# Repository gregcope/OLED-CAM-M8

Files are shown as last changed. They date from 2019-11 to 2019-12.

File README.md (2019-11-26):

# OLED-CAM-M8
OLED / NEO CAM M8Q Board is designed to go above other boards so that;
1. The GNS has a large ground plane for its internal attenna
2. The GNS has nothing near its antenna so that it has a good view of the sky
3. The OLED is ontop

More to follow... if it works

# Version
1. OLED-CAM-M8_2019-11-25.zip sent to fab

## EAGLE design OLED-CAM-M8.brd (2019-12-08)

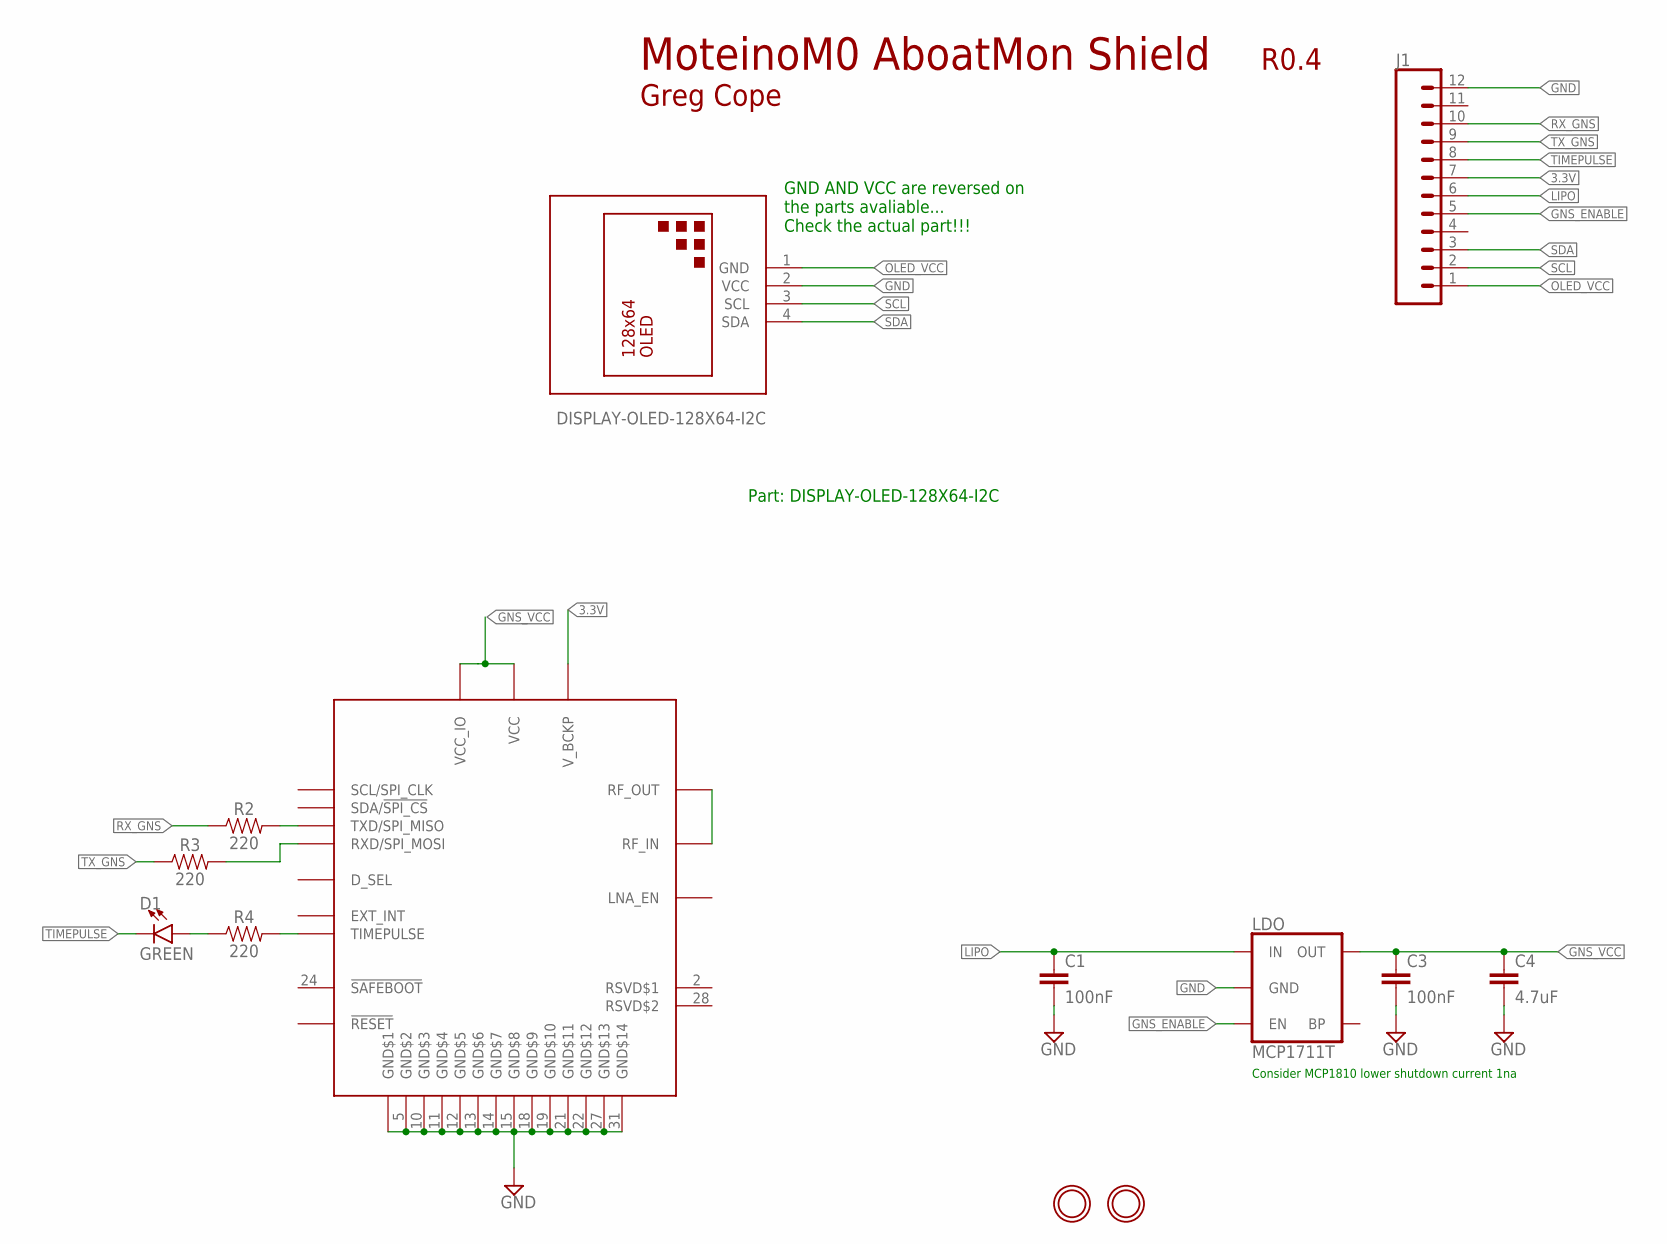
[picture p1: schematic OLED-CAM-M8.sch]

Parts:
C1, C3: 100nF; 0603
C4: 4.7uF; 0603
D1: GREEN; LED-0603
GND: MOUNTINGHOLE2.5; MOUNTINGHOLE_2.5_PLATED
J1: CONN_12; 1X12
LDO: MCP1711T; SOT23-5
R2, R3, R4: 220; 0603
U$2: DISPLAY-OLED-128X64-I2C
U$5: CAM-M8
U$7: MOUNTINGHOLE2.5; MOUNTINGHOLE_2.5_PLATED

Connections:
3.3V: J1.7, U$5.8 (V_BCKP)
GND: C1.2, C3.2, C4.2, J1.12, LDO.2 (GND), U$2.2 (VCC), U$5.4 (GND$1), U$5.5 (GND$2), U$5.10 (GND$3), U$5.11 (GND$4), U$5.12 (GND$5), U$5.13 (GND$6), U$5.14 (GND$7), U$5.15 (GND$8), U$5.18 (GND$9), U$5.19 (GND$10), U$5.21 (GND$11), U$5.22 (GND$12), U$5.27 (GND$13), U$5.31 (GND$14)
GNS_ENABLE: J1.5, LDO.3 (EN)
GNS_VCC: C3.1, C4.1, LDO.5 (OUT), U$5.1 (VCC_IO), U$5.9 (VCC)
LIPO: C1.1, J1.6, LDO.1 (IN)
unnamed: R4.2, U$5.29 (TIMEPULSE)
unnamed: R2.2, U$5.25 (TXD/SPI_MISO)
unnamed: R3.2, U$5.26 (RXD/SPI_MOSI)
unnamed: D1.A, R4.1
unnamed: U$5.16 (RF_OUT), U$5.17 (RF_IN)
OLED_VCC: J1.1, U$2.1 (GND)
RX_GNS: J1.10, R2.1
SCL: J1.2, U$2.3 (SCL)
SDA: J1.3, U$2.4 (SDA)
TIMEPULSE: D1.C, J1.8
TX_GNS: J1.9, R3.1

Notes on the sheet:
Greg Cope
R0.4
MoteinoM0 AboatMon Shield
Consider MCP1810 lower shutdown current 1na
Part: DISPLAY-OLED-128X64-I2C
GND AND VCC are reversed on the parts avaliable... Check the actual part!!!

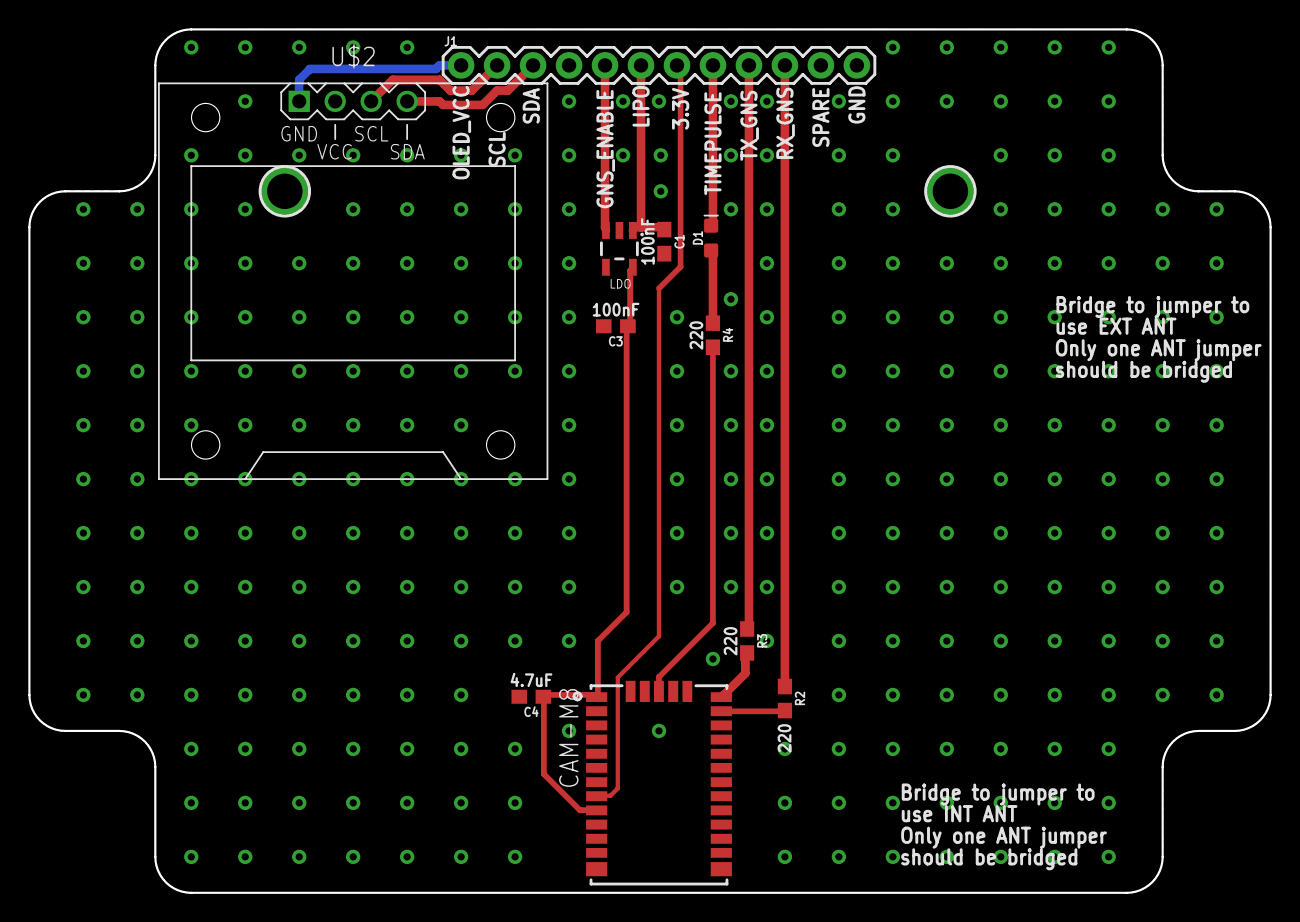
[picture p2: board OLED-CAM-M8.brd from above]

Board: 2 copper layers, 87.6 x 61.0 mm, 13 parts (0 on the bottom side), 16 nets.

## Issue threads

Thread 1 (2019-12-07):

OLED header / outline wrong

gregcope, 2019-12-07:
Header/outline is wrong for most OLEDs I have.

They are from left to right (from above);
VCC
GND
SCL
SDA

gregcope, 2019-12-08:
Swapped the Pins and left a note.  Seems some screens are supplied with pins swapped, others not.  Fixed(!) in 8a7cde8

Closed 2019-12-08.

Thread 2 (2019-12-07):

Mount holes do not line up

gregcope, 2019-12-07:
With this outline they do not line up

gregcope, 2019-12-08:
They do ... but only just.  Not an issue.  User error.

Closed 2019-12-08.

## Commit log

2019-11-25 DRC, ERC pass
    [OLED-CAM-M8.brd, OLED-CAM-M8.sch]
2019-11-25 Added GND vias and notes
    [OLED-CAM-M8.brd]
2019-11-25 Added mounting hole
    [OLED-CAM-M8.brd, OLED-CAM-M8.sch]
2019-12-08 Swapped VCC GND
    [OLED-CAM-M8.brd, OLED-CAM-M8.sch]
2019-12-08 removed mounting hole and moved 100n cap
    [OLED-CAM-M8.brd, OLED-CAM-M8.sch]
2019-12-08 moved 3v rail
    [OLED-CAM-M8.brd]
2019-12-08 removed ufl and jumpers
    [OLED-CAM-M8.brd, OLED-CAM-M8.sch]

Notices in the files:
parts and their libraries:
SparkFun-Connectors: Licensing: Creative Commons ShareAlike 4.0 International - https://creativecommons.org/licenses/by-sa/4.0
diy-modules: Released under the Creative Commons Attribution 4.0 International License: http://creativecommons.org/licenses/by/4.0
